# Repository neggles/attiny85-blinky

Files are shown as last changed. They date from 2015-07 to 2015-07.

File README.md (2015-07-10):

# attiny85-blinky
Arduino blinky shenanigans for ATtiny85/Gemma/Trinket and WS2812B LEDs.

This was written and tested using the Arduino ATtiny core from http://highlowtech.org/?p=1695, but ought to work with other cores.

Uses a hardware pin-change interrupt, and the Adafruit Neopixel library.

It has been confirmed to operate on an Adafruit GEMMA and 3.3v Trinket, though it's important to note that if your cheap WS2812B LEDs are receiving over ~4v VCC, a 3.3v micro may not be able to push the DIN pin hard enough.

Also included is an eagle .brd/.sch pair for a small CR2032-powered widget with a SOIC ATTiny85 and 4 LEDs.
Battery life isn't amazing, and you should omit/bridge the 3.3v regulator if you want it to work under USB power, so it's not perfect, but it's neat.
(I'm not actually sure why I kept the 3.3v regulator, if we're honest. It does very little at best.)

PCBs can be bought directly from OSHPark here, at about six bucks for 3: https://oshpark.com/shared_projects/sMGC09Kl

Here's a pic of a couple I made, sans USB connections since I hadn't received the sockets at this point; http://i.imgur.com/KQKQHtf.jpg

Otherwise, this code is fairly flexible and modular (on purpose) and I tried to comment it as best I could.

Let me know what you think :)

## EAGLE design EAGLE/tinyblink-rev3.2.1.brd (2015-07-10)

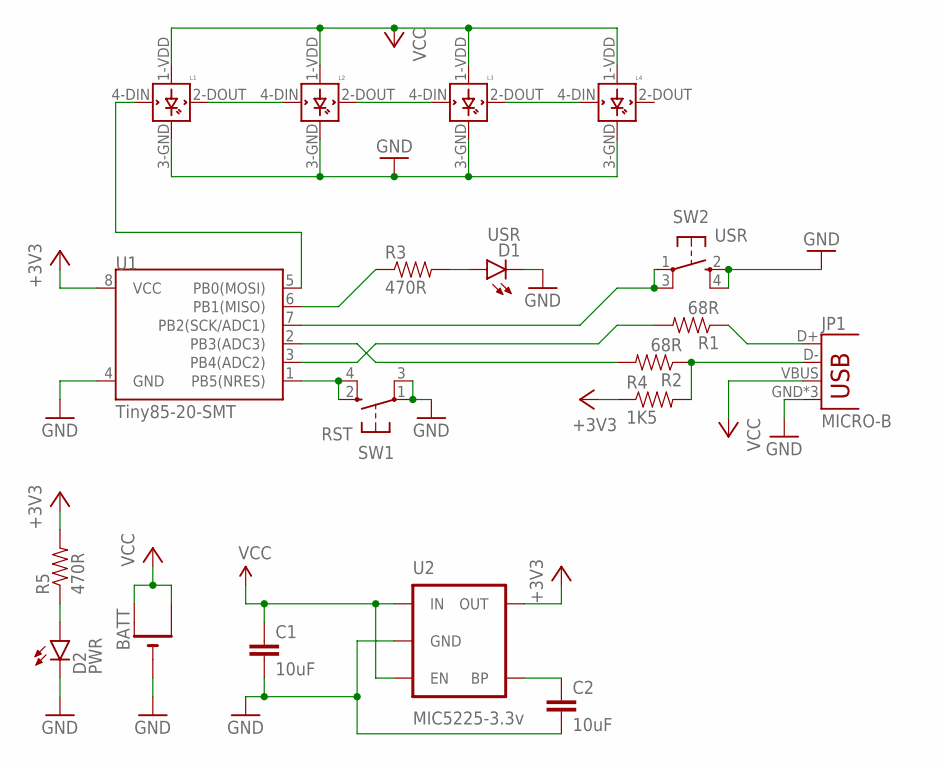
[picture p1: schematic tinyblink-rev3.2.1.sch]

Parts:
BATT: CR2032SMT; CR2032-SMD
C1, C2: 10uF; 0603-CAP
D1: USR; LED-0603
D2: PWR; LED-0603
JP1: MICRO-B; USB-MICROB
L1, L2, L3, L4: WS2812B
R1, R2: 68R; 0603-RES
R3, R5: 470R; 0603-RES
R4: 1K5; 0603-RES
SW1: RST; KMR2
SW2: USR; KMR2
U1: Tiny85-20-SMT; SO08-EIAJ
U2: MIC5225-3.3v; SOT23-5

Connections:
+3V3: R4.1, R5.2, U1.8 (VCC), U2.5 (OUT)
GND: BATT.-, C1.2, C2.2, D1.C, D2.C, JP1.GND, JP1.MT1 (GND), JP1.MT2 (GND), L1.3-GND (GND), L2.3-GND (GND), L3.3-GND (GND), L4.3-GND (GND), SW1.1, SW1.3 (P1), SW2.2 (S), SW2.4 (S1), U1.4 (GND), U2.2 (GND)
unnamed: SW1.2 (S), SW1.4 (S1), U1.1 (PB5(NRES))
unnamed: SW2.1, SW2.3 (P1), U1.7 (PB2(SCK/ADC1))
unnamed: L1.4-DIN (DIN), U1.5 (PB0(MOSI))
unnamed: D1.A, R3.2
unnamed: JP1.D+, R1.1
unnamed: JP1.D-, R2.1, R4.2
unnamed: C2.1, U2.4 (BP)
unnamed: L1.2-DOUT (DOUT), L2.4-DIN (DIN)
unnamed: R2.2, U1.2 (PB3(ADC3))
unnamed: D2.A, R5.1
unnamed: R1.2, U1.3 (PB4(ADC2))
unnamed: L2.2-DOUT (DOUT), L3.4-DIN (DIN)
unnamed: L3.2-DOUT (DOUT), L4.4-DIN (DIN)
unnamed: R3.1, U1.6 (PB1(MISO))
VCC: BATT.+$1 (+), BATT.+$2 (+1), C1.1, JP1.VBUS, L1.1-VDD (VDD), L2.1-VDD (VDD), L3.1-VDD (VDD), L4.1-VDD (VDD), U2.1 (IN), U2.3 (EN)

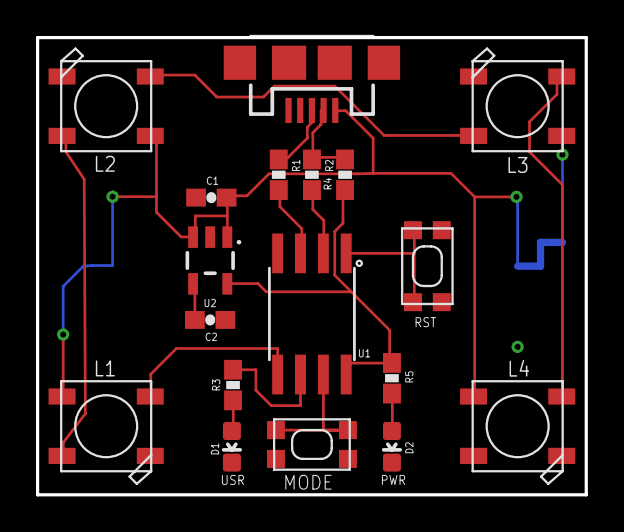
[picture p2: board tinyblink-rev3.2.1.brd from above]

Board: 2 copper layers, 30.5 x 25.4 mm, 19 parts (1 on the bottom side), 17 nets.

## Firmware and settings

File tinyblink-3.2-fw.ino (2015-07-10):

/*
 * WS2812B blinkenlight firmware using an ATTiny85
 * Should work with Adafruit Trinket and Gemma also
 * CC BY-NC-SA 4.0 license
 * Andrew Holmes 2015
 * 
 * Status LED will toggle with every button press.
 * Operates at no faster than 50fps, with a frame counter.
 * At least in theory. I have no idea if that works.
 */

#include <Adafruit_NeoPixel.h> 
#define LEDS 4  // Number of LEDS in your NeoPixel string 
#define DTAPIN 0 // LED string data pin
#define LEDPIN 1 // Status LED pin. TBH, I'm not really using this,  but it's on my PCB.
#define BTNPIN 2 // Button pin. This uses a pinchange interrupt, and has the internal pullup enabled. 
#define BTNDLY 250 // Debounce delay on button.
#define STPBRT 64 // Strip brightness.

// Start NeoPixel
Adafruit_NeoPixel strip = Adafruit_NeoPixel(LEDS, DTAPIN, NEO_GRB + NEO_KHZ800);

// The following is pin change interrupt black magic.
#ifndef cbi
#define cbi(sfr, bit) (_SFR_BYTE(sfr) &= ~_BV(bit))
#endif
#ifndef sbi
#define sbi(sfr, bit) (_SFR_BYTE(sfr) |= _BV(bit))
#endif

// Global Variables
uint8_t pattern = 1; // Pattern selection
uint8_t counter = 0; 
uint8_t frame_delay = 20; // 20ms/frame, ~50fps.
uint8_t colors[3];
uint8_t hue = 200;
uint8_t myPix=0;
uint8_t lastPix=0;
uint32_t setColor=0;
bool LEDstate = false;
bool firstrun = true;
bool even = false;
volatile unsigned long debounce = 0; // counter for debounce reasons
volatile unsigned long framecount = 0; // counter for FPS reasons

void setup() {
  pinMode(BTNPIN, INPUT_PULLUP);
  pinMode(LEDPIN, OUTPUT);
  toggleLED(); // turn on status light so we know it's booted
  
  sbi(GIMSK,PCIE);   // Turn on Pin Change interrupt, somehow. I don't know. Registers, man.
  sbi(PCMSK,PCINT2); // Which pins are affected by the interrupt. PCINT1 = PB1 = digital pin 1 on attiny85.

  strip.begin(); // wake the kraken
  strip.show(); // Initialize all pixels to 'off'
  strip.setBrightness(STPBRT); // turn this shit down oh god so bright
}

void loop() {
  if ((millis() - framecount) > frame_delay) {
    framecount = millis();
    switchPattern(pattern); // Generate next frame
    strip.show(); // Push frame to strip
    counter++; // Increment universal per-pattern counter
  }
  if (counter > 255) { 
   counter = 0;
  }
}

/* pick a pattern */
void switchPattern(uint8_t var) {
      switch (var) {
        case 1:
          // show rainbow
          rainbowCycle();
        break;
        case 2:
          // Randomly light a pixel.
          randomGlowy();
        break;
        case 3:
          fadeEvenOdd();
        break;    
//        case 4:
          // rainbow firefly, 1px at random
//          colorFirefly();
//        break;
        default: // Reset pattern to #1 if selected pattern number is over number of patterns
         pattern = 1; 
        break;
      }
}

// ------------------------------------------------------------------------------
// Patterns section;

// Cycles a rainbow across the LEDs
void rainbowCycle() {
  if(firstrun == true) { setFramerate(60); firstrun = false; }
    for (int i = 0; i < strip.numPixels(); i++) {
        strip.setPixelColor(i, Wheel(((i * 256 / strip.numPixels()) + counter) & 255));
    }
    
}

// Picks a random LED and makes it a random color.
void randomGlowy() {
  if(firstrun == true) { setFramerate(10); firstrun = false; }
   strip.setPixelColor(random(LEDS),Wheel(random(360)));
}

// Pulse even/odd pixels

void fadeEvenOdd() {
  if(firstrun == true) { setFramerate(250); firstrun = false; hue = random(360); }
  if(even == true) { fadeEven(); } else { fadeOdd(); }
}

void fadeEven () {
  if(counter < 128) {
    for (int i = 0; i < strip.numPixels(); i++) {
      if (i % 2) {
        HSVtoRGB(hue,255,(counter)*2,colors);
        strip.setPixelColor(i,colors[0],colors[1],colors[2]);
      }
    }
  } else {
    for (int i = 0; i < strip.numPixels(); i++) {
      if (i % 2) {
        HSVtoRGB(hue,255,255-((counter-128)*2),colors);
        strip.setPixelColor(i,colors[0],colors[1],colors[2]);
      }
    }
  }
  if(counter == 254) {
    even = false;
    hue = random(360);
  }
}

void fadeOdd() {  
  if(counter < 128) {
    for (int i = 0; i < strip.numPixels(); i++) {
      if (!(i % 2)) {
        HSVtoRGB(hue,255,(counter)*2,colors);
        strip.setPixelColor(i,colors[0],colors[1],colors[2]);
      }
    }
  } else {
    for (int i = 0; i < strip.numPixels(); i++) {
      if (!(i % 2)) {
        HSVtoRGB(hue,255,255-((counter-128)*2),colors);
        strip.setPixelColor(i,colors[0],colors[1],colors[2]);
      }
    }
  }
  if(counter == 254) {
    even = true;
    hue = random(360);
  }
}

/* // dat firefly tho
void colorFirefly() {
  if(firstrun == true) { setFramerate(10); firstrun = false; }
  if(myPix != lastPix) {
    if(counter<16) {
      int colorV = sin((6.28/30)*(float)(counter)) *255;
      HSVtoRGB((359/16)*counter, 255, colorV, colors);
      strip.setPixelColor(myPix, colors[0], colors[1], colors[2]);
    } else {
      lastPix=myPix;
      counter=0;
      colorFast(0);
    }
  } else {
    myPix=random(0,strip.numPixels());
  }
}*/

// ------------------------------------------------------------------------------
// System section;

void setFramerate(uint8_t framerate) {
  frame_delay = (1000 / framerate);
}

void toggleLED() { // if LED is on, turn it off. if LED is off, turn it on.
  if(LEDstate == true) {
    digitalWrite(LEDPIN, LOW);
    LEDstate = false;
  } else {
    digitalWrite(LEDPIN, HIGH);
    LEDstate = true; 
  }
}

ISR(PCINT0_vect) { // This is the shit that runs on the PCInt triggering.
  if (digitalRead(BTNPIN) == LOW && (millis() - debounce) > BTNDLY) {
    debounce = millis();
    counter = 0;
    pattern++;
    firstrun = true;
    colorFast(0);
    toggleLED();
  }
}

// manipulation helpers 

// Write a color to the whole string
void colorFast(uint32_t c) {
    for (uint16_t i = 0; i < strip.numPixels(); i++) {
        strip.setPixelColor(i, c);
    }
    strip.show();
}

uint32_t Wheel(byte WheelPos) {
    if (WheelPos < 85) {
        return strip.Color(WheelPos * 3, 255 - WheelPos * 3, 0);
    } else if (WheelPos < 170) {
        WheelPos -= 85;
        return strip.Color(255 - WheelPos * 3, 0, WheelPos * 3);
    } else {
        WheelPos -= 170;
        return strip.Color(0, WheelPos * 3, 255 - WheelPos * 3);
    }
}


// HSV to RGB colors
// hue: 0-359, sat: 0-255, val (lightness): 0-255
// adapted from http://funkboxing.com/wordpress/?p=1366
void HSVtoRGB(int hue, int sat, int val, uint8_t * colors) {
    int r, g, b, base;
    if (sat == 0) { // Achromatic color (gray).
        colors[0] = val;
        colors[1] = val;
        colors[2] = val;
    } else {
        base = ((255 - sat) * val) >> 8;
        switch (hue / 60) {
        case 0:
            colors[0] = val;
            colors[1] = (((val - base) * hue) / 60) + base;
            colors[2] = base;
            break;
        case 1:
            colors[0] = (((val - base) * (60 - (hue % 60))) / 60) + base;
            colors[1] = val;
            colors[2] = base;
            break;
        case 2:
            colors[0] = base;
            colors[1] = val;
            colors[2] = (((val - base) * (hue % 60)) / 60) + base;
            break;
        case 3:
            colors[0] = base;
            colors[1] = (((val - base) * (60 - (hue % 60))) / 60) + base;
            colors[2] = val;
            break;
        case 4:
            colors[0] = (((val - base) * (hue % 60)) / 60) + base;
            colors[1] = base;
            colors[2] = val;
            break;
        case 5:
            colors[0] = val;
            colors[1] = base;
            colors[2] = (((val - base) * (60 - (hue % 60))) / 60) + base;
            break;
        }

    }
}

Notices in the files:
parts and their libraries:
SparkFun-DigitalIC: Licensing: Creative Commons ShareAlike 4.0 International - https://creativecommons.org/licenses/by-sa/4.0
